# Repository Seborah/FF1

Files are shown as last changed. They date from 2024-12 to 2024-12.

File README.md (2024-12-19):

# FF1
The first ForgFactory keyboard

A fully custom USB-C numpad made with an ATMEGA32U4 and QMK.

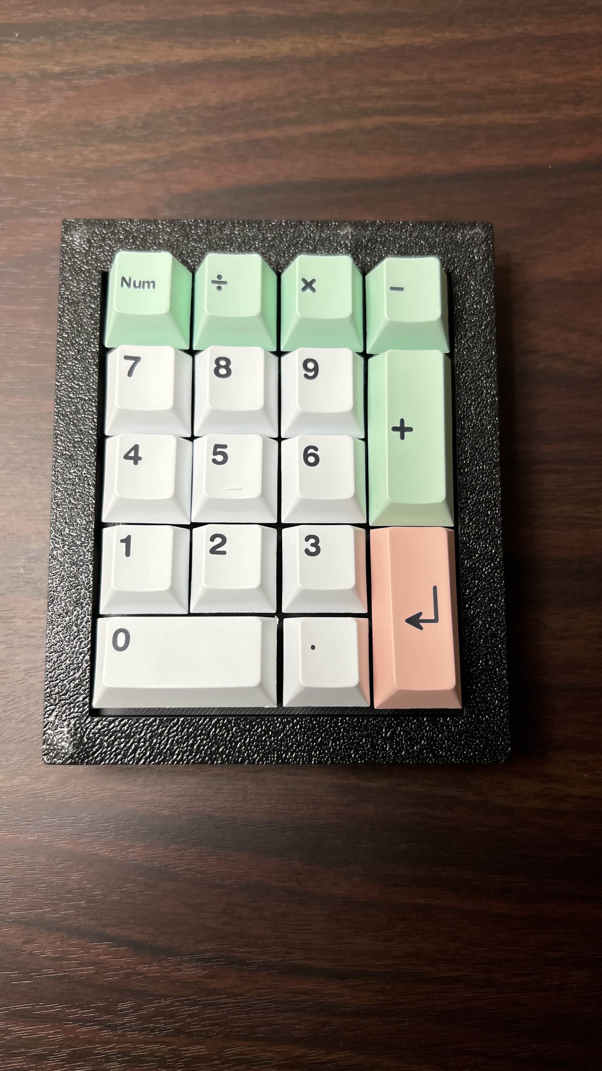
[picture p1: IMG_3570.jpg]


# Kicanvas
[Daughter Board](https://kicanvas.org/?github=https%3A%2F%2Fgithub.com%2FSeborah%2FFF1%2Ftree%2Fmain%2Fdaughter%2520board)
[Button Board](https://kicanvas.org/?github=https%3A%2F%2Fgithub.com%2FSeborah%2FFF1%2Ftree%2Fmain%2Fbutton%2520pcb)

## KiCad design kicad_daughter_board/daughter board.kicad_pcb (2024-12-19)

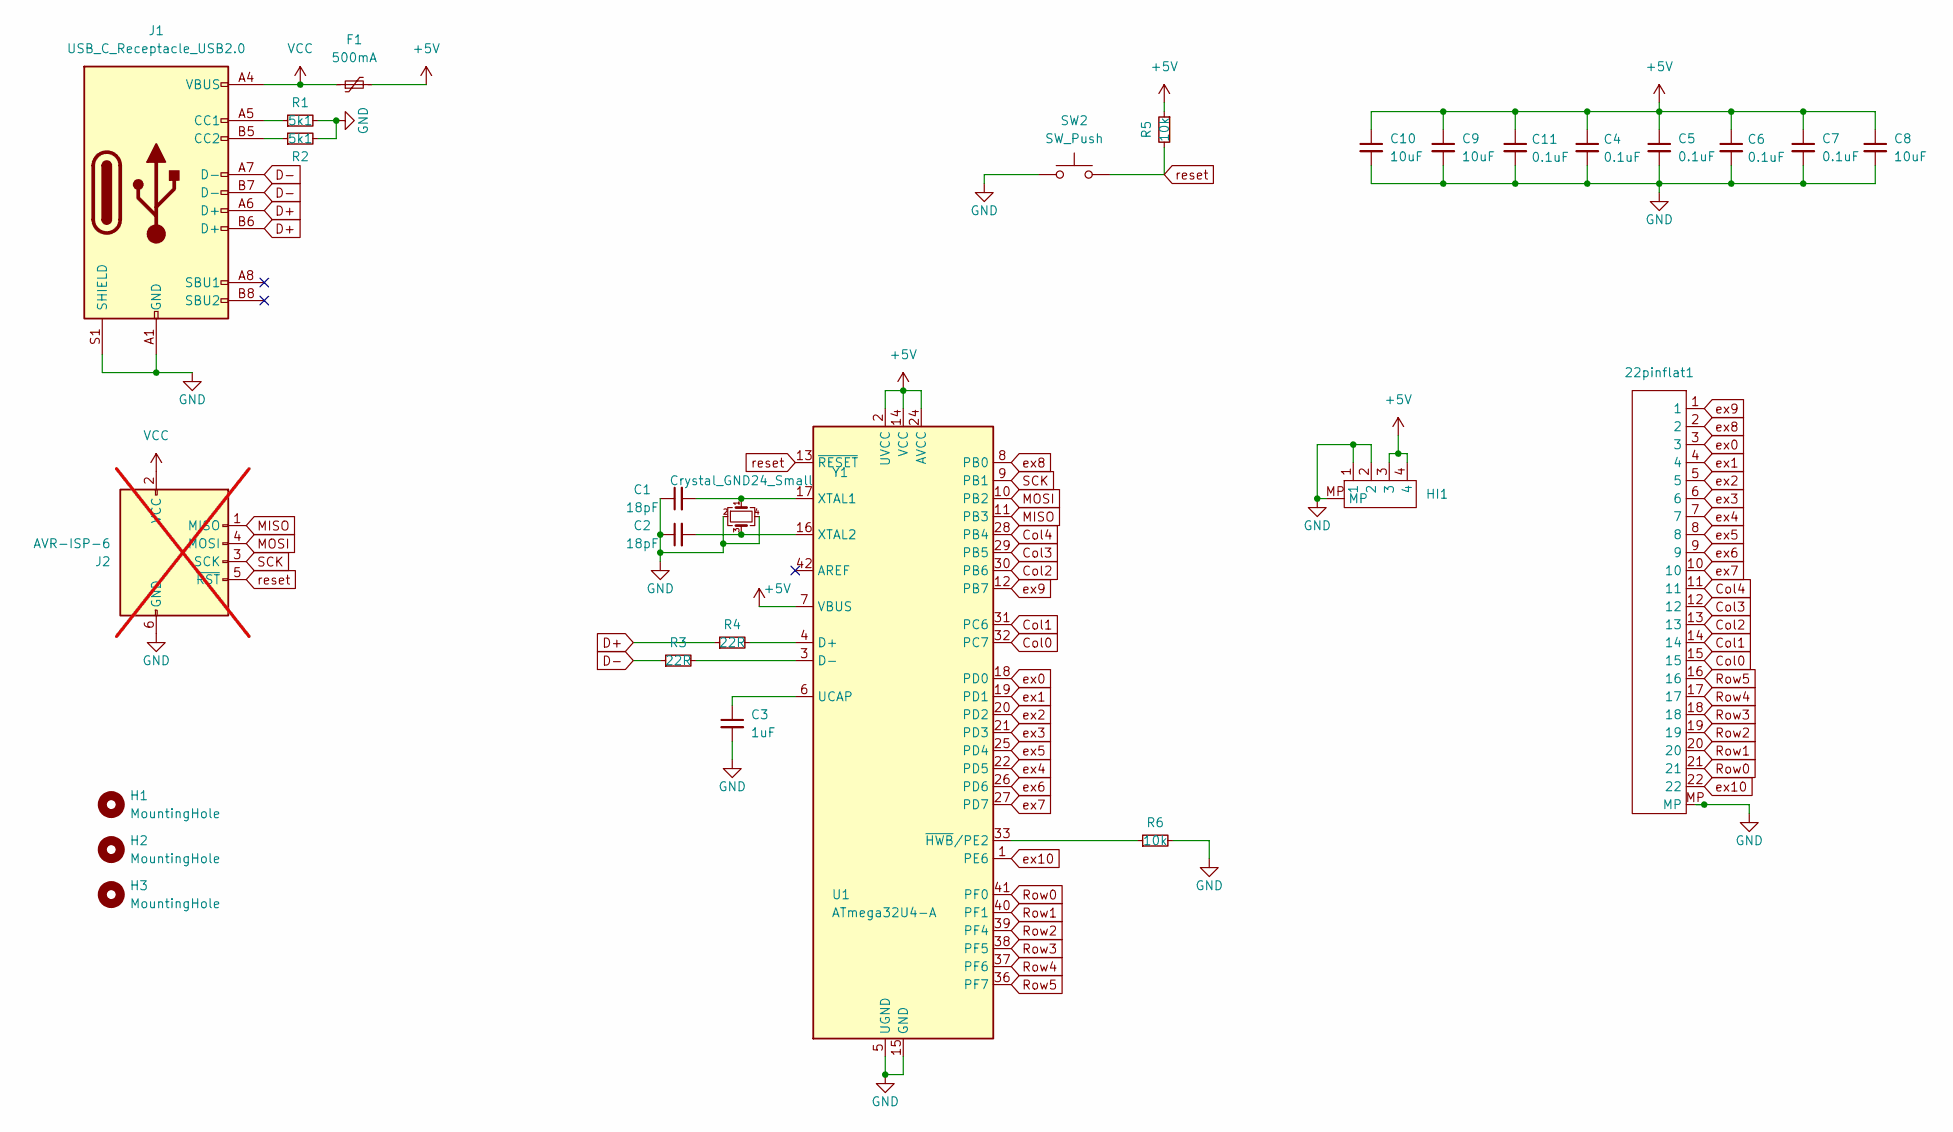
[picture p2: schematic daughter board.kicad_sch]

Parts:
22pinflat1: TE_2-1734839-2_1x22-1MP_P0.5mm_Horizontal
C1, C2: 18pF; C_0805_2012Metric
C3: 1uF; C_0805_2012Metric
C4, C5, C6, C7, C11: 0.1uF; C_0805_2012Metric
C8, C9, C10: 10uF; C_0805_2012Metric
F1: 500mA; Fuse_1206_3216Metric
H1, H2, H3: MountingHole; MountingHole_2.5mm_Pad
HI1: Hirose_DF52-4S-0.8H_1x04-1MP_P0.80mm_Horizontal
J1: USB_C_Receptacle_USB2.0; USB_C_Receptacle_HCTL_HC-TYPE-C-16P-01A
J2: AVR-ISP-6; IDC-Header_2x03_P2.54mm_Vertical; not fitted
R1, R2: 5k1; R_0805_2012Metric
R3, R4: 22R; R_0805_2012Metric
R5, R6: 10k; R_0805_2012Metric
SW2: SW_Push; SW_SPST_SKQG_WithStem
U1: ATmega32U4-A; TQFP-44_10x10mm_P0.8mm
Y1: Crystal_GND24_Small; Crystal_SMD_3225-4Pin_3.2x2.5mm

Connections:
+5V: C4.1, C5.1, C6.1, C7.1, C8.1, C9.1, C10.1, C11.1, F1.2, HI1.3, HI1.4, R5.1, U1.2 (UVCC), U1.7 (VBUS), U1.14 (VCC), U1.24 (AVCC), U1.34 (VCC), U1.44 (AVCC)
Col0: 22pinflat1.15, U1.32 (PC7)
Col1: 22pinflat1.14, U1.31 (PC6)
Col2: 22pinflat1.13, U1.30 (PB6)
Col3: 22pinflat1.12, U1.29 (PB5)
Col4: 22pinflat1.11, U1.28 (PB4)
D+: J1.A6 (D+), J1.B6 (D+), R4.1
D-: J1.A7 (D-), J1.B7 (D-), R3.1
GND: 22pinflat1.MP, C1.1, C2.1, C3.2, C4.2, C5.2, C6.2, C7.2, C8.2, C9.2, C10.2, C11.2, HI1.1, HI1.2, HI1.MP, J1.A1 (GND), J1.A12 (GND), J1.B1 (GND), J1.B12 (GND), J1.S1 (SHIELD), J2.6 (GND), R1.2, R2.2, R6.2, SW2.1, U1.5 (UGND), U1.15 (GND), U1.23 (GND), U1.35 (GND), U1.43 (GND), Y1.2, Y1.4
MISO: J2.1 (MISO), U1.11 (PB3)
MOSI: J2.4 (MOSI), U1.10 (PB2)
unnamed: J1.A5 (CC1), R1.1
unnamed: J1.B5 (CC2), R2.1
unnamed: R4.2, U1.4 (D+)
unnamed: R3.2, U1.3 (D-)
unnamed: C3.1, U1.6 (UCAP)
unnamed: C1.2, U1.17 (XTAL1), Y1.1
unnamed: C2.2, U1.16 (XTAL2), Y1.3
unnamed: R6.1, U1.33 (~HWB/PE2)
Row0: 22pinflat1.21, U1.41 (PF0)
Row1: 22pinflat1.20, U1.40 (PF1)
Row2: 22pinflat1.19, U1.39 (PF4)
Row3: 22pinflat1.18, U1.38 (PF5)
Row4: 22pinflat1.17, U1.37 (PF6)
Row5: 22pinflat1.16, U1.36 (PF7)
SCK: J2.3 (SCK), U1.9 (PB1)
VCC: F1.1, J1.A4 (VBUS), J1.A9 (VBUS), J1.B4 (VBUS), J1.B9 (VBUS), J2.2 (VCC)
ex0: 22pinflat1.3, U1.18 (PD0)
ex1: 22pinflat1.4, U1.19 (PD1)
ex2: 22pinflat1.5, U1.20 (PD2)
ex3: 22pinflat1.6, U1.21 (PD3)
ex4: 22pinflat1.7, U1.22 (PD5)
ex5: 22pinflat1.8, U1.25 (PD4)
ex6: 22pinflat1.9, U1.26 (PD6)
ex7: 22pinflat1.10, U1.27 (PD7)
ex8: 22pinflat1.2, U1.8 (PB0)
ex9: 22pinflat1.1, U1.12 (PB7)
ex10: 22pinflat1.22, U1.1 (PE6)
reset: J2.5 (~RST), R5.2, SW2.2, U1.13 (~RESET)

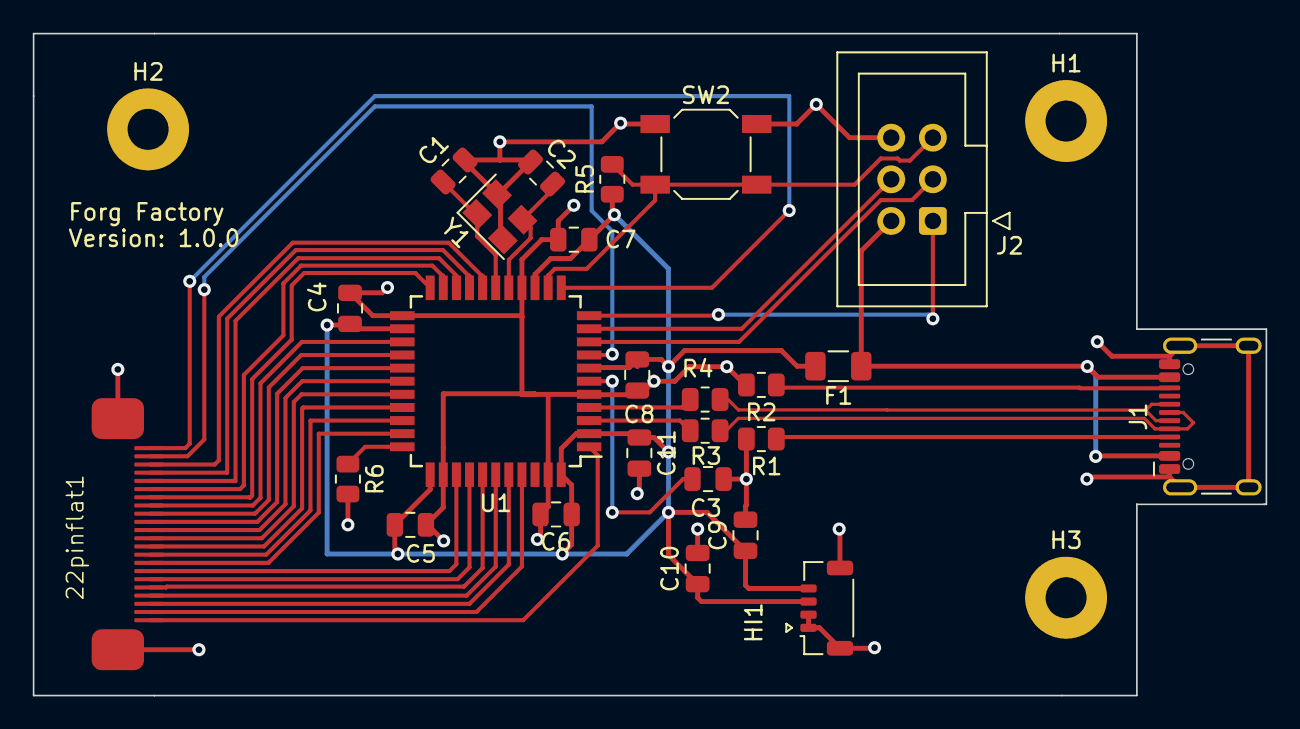
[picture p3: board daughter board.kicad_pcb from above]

Board: 2 copper layers, 75.2 x 40.4 mm, 28 parts (0 on the bottom side), 39 nets.

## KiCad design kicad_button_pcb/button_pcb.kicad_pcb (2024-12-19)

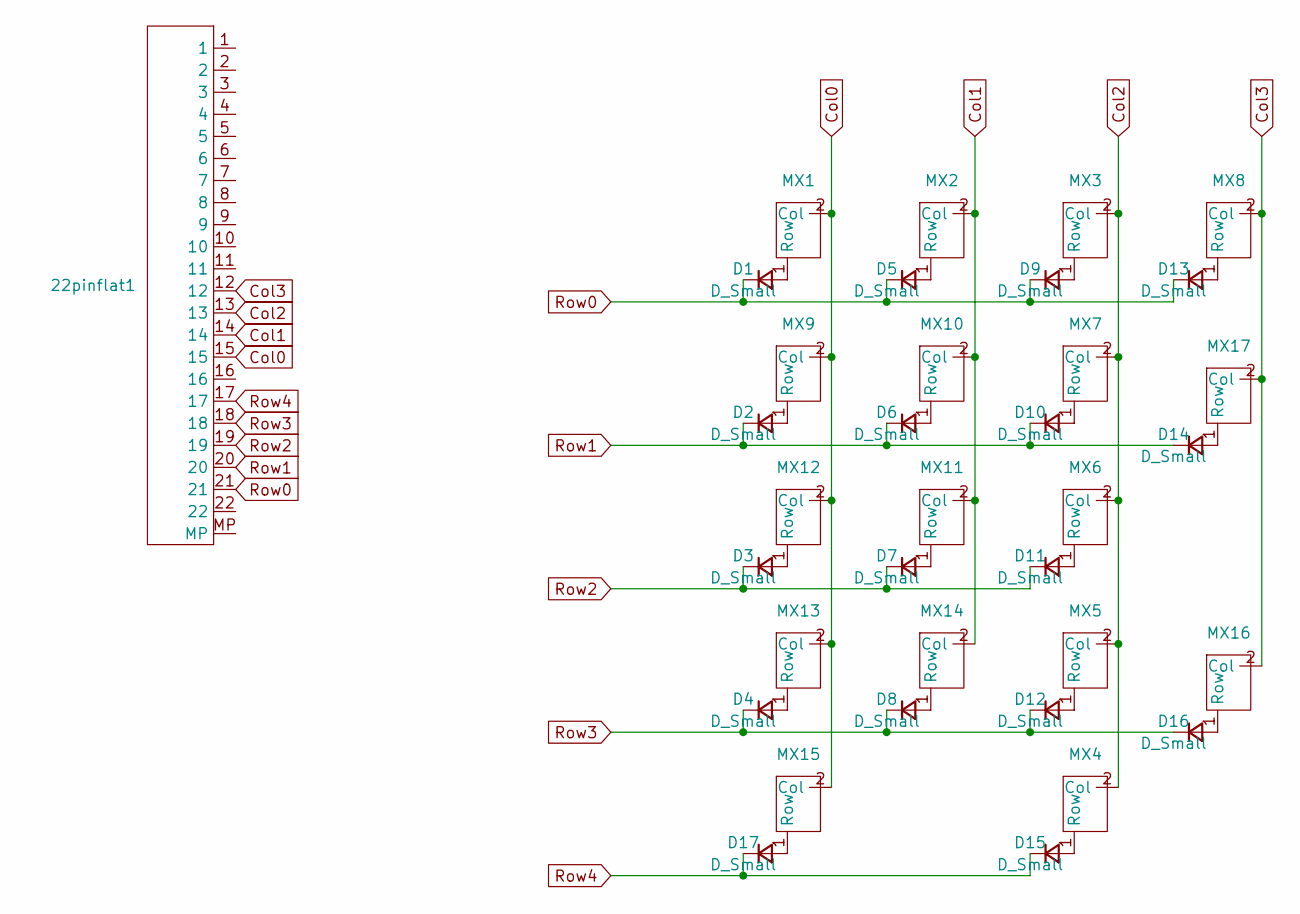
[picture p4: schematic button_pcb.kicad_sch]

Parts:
22pinflat1: Hirose_FH12-22S-0.5SH_1x22-1MP_P0.50mm_Horizontal
D1, D2, D3, D4, D5, D6, D7, D8, D9, D10, D11, D12, D13, D14, D15, D16, D17: D_Small; D_SOD-123
MX1, MX2, MX3, MX4, MX5, MX6, MX7, MX8, MX9, MX10, MX11, MX12, MX13, MX14: MX-Hotswap-1U
MX15: MX-Hotswap-2U-ReversedStabilizers
MX16, MX17: MX-Hotswap-2U-Vertical

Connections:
Col0: 22pinflat1.15, MX1.2 (Col), MX9.2 (Col), MX12.2 (Col), MX13.2 (Col), MX15.2 (Col)
Col1: 22pinflat1.14, MX2.2 (Col), MX10.2 (Col), MX11.2 (Col), MX14.2 (Col)
Col2: 22pinflat1.13, MX3.2 (Col), MX4.2 (Col), MX5.2 (Col), MX6.2 (Col), MX7.2 (Col)
Col3: 22pinflat1.12, MX8.2 (Col), MX16.2 (Col), MX17.2 (Col)
unnamed: D1.2 (A), MX1.1 (Row)
unnamed: D2.2 (A), MX9.1 (Row)
unnamed: D3.2 (A), MX12.1 (Row)
unnamed: D4.2 (A), MX13.1 (Row)
unnamed: D5.2 (A), MX2.1 (Row)
unnamed: D6.2 (A), MX10.1 (Row)
unnamed: D7.2 (A), MX11.1 (Row)
unnamed: D8.2 (A), MX14.1 (Row)
unnamed: D9.2 (A), MX3.1 (Row)
unnamed: D10.2 (A), MX7.1 (Row)
unnamed: D11.2 (A), MX6.1 (Row)
unnamed: D12.2 (A), MX5.1 (Row)
unnamed: D13.2 (A), MX8.1 (Row)
unnamed: D14.2 (A), MX17.1 (Row)
unnamed: D15.2 (A), MX4.1 (Row)
unnamed: D16.2 (A), MX16.1 (Row)
unnamed: D17.2 (A), MX15.1 (Row)
Row0: 22pinflat1.21, D1.1 (K), D5.1 (K), D9.1 (K), D13.1 (K)
Row1: 22pinflat1.20, D2.1 (K), D6.1 (K), D10.1 (K), D14.1 (K)
Row2: 22pinflat1.19, D3.1 (K), D7.1 (K), D11.1 (K)
Row3: 22pinflat1.18, D4.1 (K), D8.1 (K), D12.1 (K), D16.1 (K)
Row4: 22pinflat1.17, D15.1 (K), D17.1 (K)

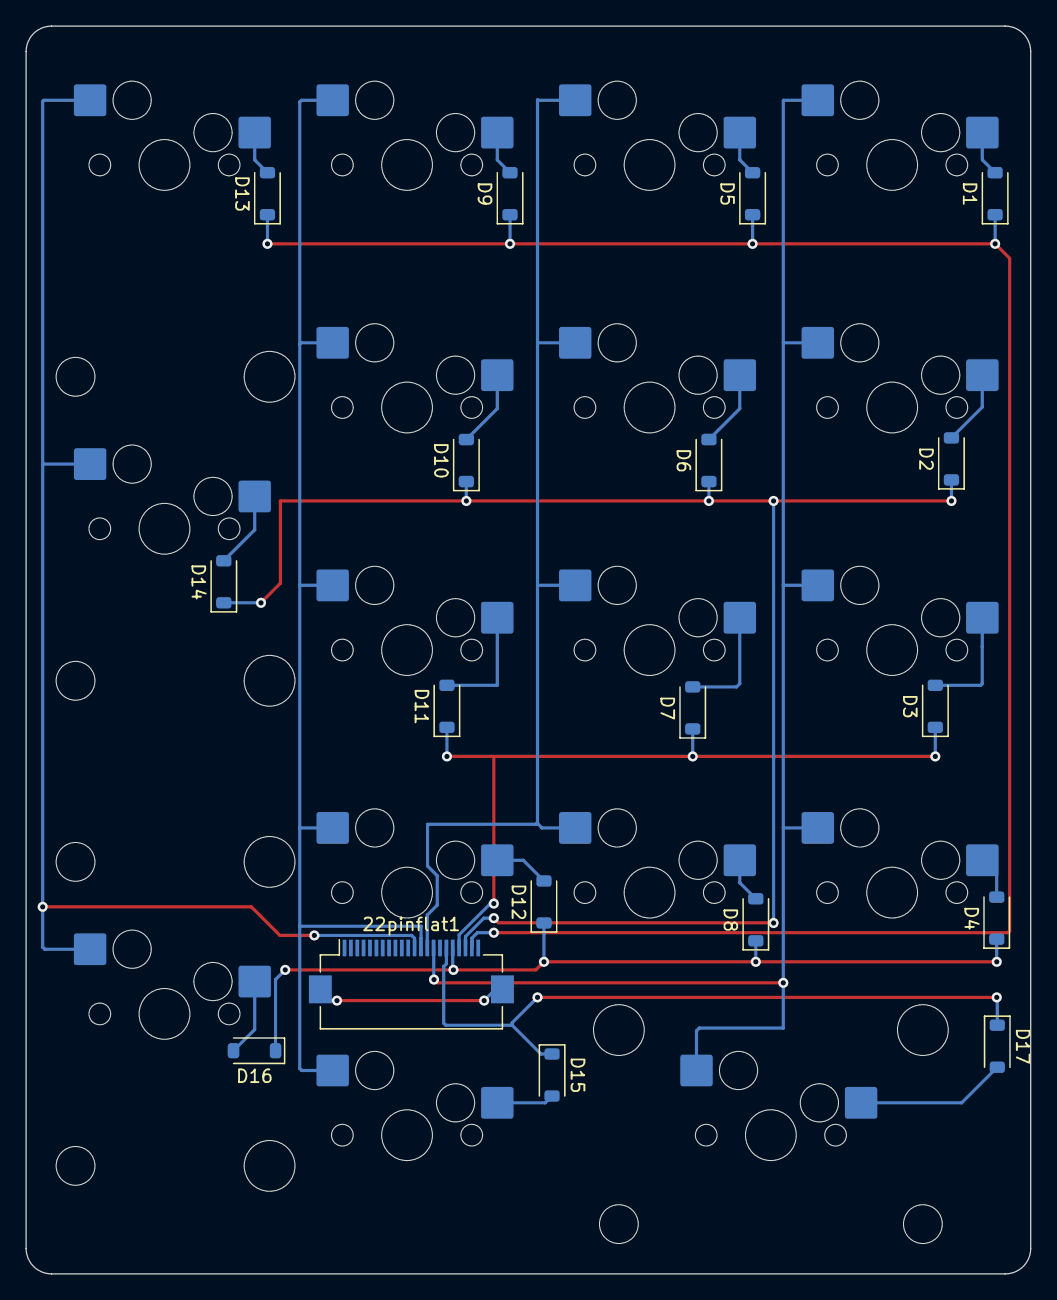
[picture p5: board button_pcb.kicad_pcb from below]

Board: 2 copper layers, 78.9 x 98.0 mm, 35 parts (18 on the bottom side), 26 nets.

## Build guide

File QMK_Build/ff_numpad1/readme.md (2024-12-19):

# ff_numpad1

ff_numpad1

*A short description of the keyboard/project*

* Keyboard Maintainer: [Seborah](https://github.com/Seborah)
* Hardware Supported: *The PCBs, controllers supported*
* Hardware Availability: *Links to where you can find this hardware*

Make example for this keyboard (after setting up your build environment):

    make ff_numpad1:default

Flashing example for this keyboard:

    make ff_numpad1:default:flash

See the [build environment setup](https://docs.qmk.fm/#/getting_started_build_tools) and the [make instructions](https://docs.qmk.fm/#/getting_started_make_guide) for more information. Brand new to QMK? Start with our [Complete Newbs Guide](https://docs.qmk.fm/#/newbs).

## Bootloader

Enter the bootloader in 3 ways:

* **Bootmagic reset**: Hold down the key at (0,0) in the matrix (usually the top left key or Escape) and plug in the keyboard
* **Physical reset button**: Briefly press the button on the back of the PCB - some may have pads you must short instead
* **Keycode in layout**: Press the key mapped to `QK_BOOT` if it is available
